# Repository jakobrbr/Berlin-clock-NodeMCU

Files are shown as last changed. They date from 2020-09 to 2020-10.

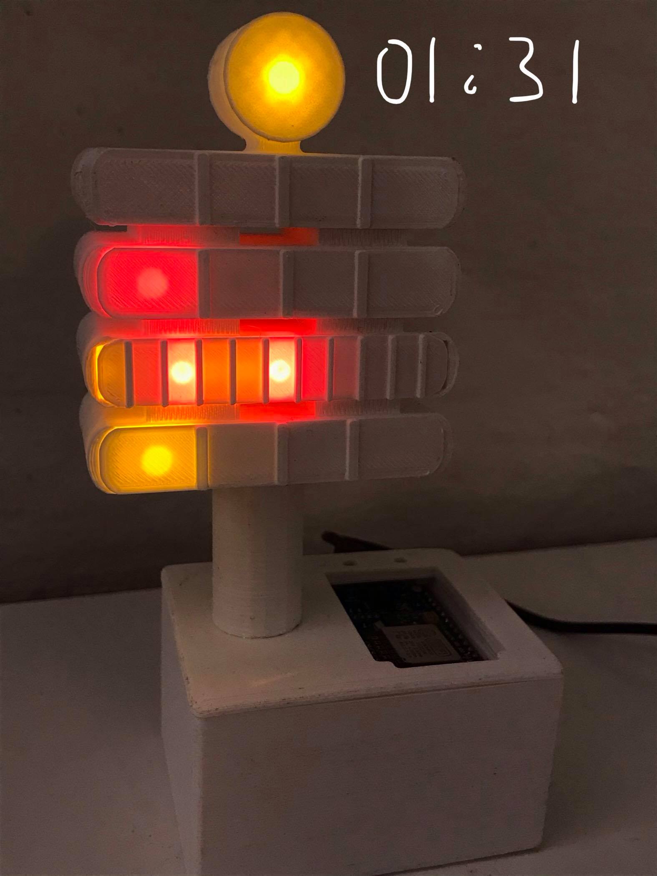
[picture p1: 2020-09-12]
Images/Front.jpg

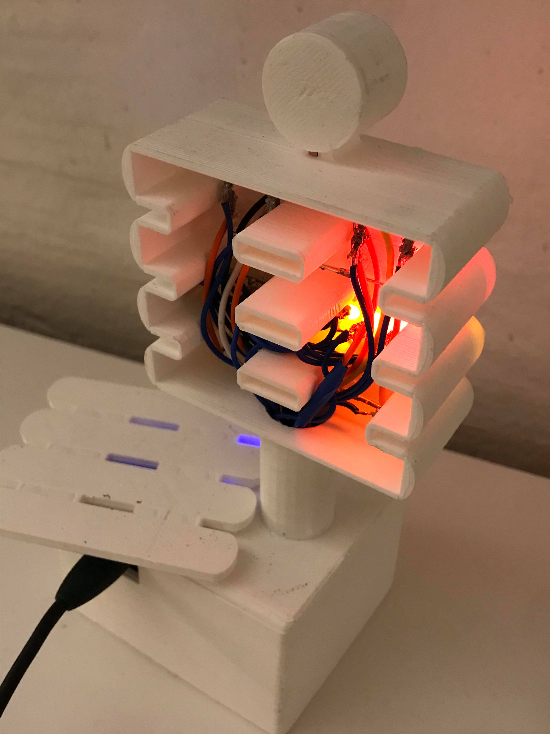
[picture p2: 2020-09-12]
Images/Back.jpg

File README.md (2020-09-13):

# Berlin-clock-NodeMCU
IoT Mengenlehreuhr aka Berlin clock made using ESP8266 NodeMCU and two 74HC595 shift registers.

The clock is based on a real clock that was installed in Berlin in 1975. My goal was to replicate the original design as best as I could, in a small "desktop form factor". 
You can read much more about the original clock and how to tell the time on [Wikipedia](https://en.wikipedia.org/wiki/Mengenlehreuhr).

This DIY version of the Berlin clock is far from perfect, since it was my first real Arduino project and my first time designing a 3d-print model. 

**Picture of the finished product:** [Front](Images/Front.jpg) and [back](Images/Back.jpg)
- As you can see, the three red 3mm LEDs I used for row 3 were too bright compared to the yellow ones. These LEDs were super bright LEDs, and I only used them because I didn't have anything else available. Normal clear 3mm LEDs would have been enough (5mm for row 1,2 and 4). 

## How it works:
The clock uses the WiFi capabilities of the NodeMCU to always have the correct time without the need of a clock module. 
When powered on, the NodeMCU connects to the internet with the network credentials you entered in the arduino code. Then the NodeMCU requests and recieves the current time from an NTP server and displays it using the 24 LEDs. The code used to get time from an NTP server comes from [randomnerdtutorials.com](https://randomnerdtutorials.com/esp8266-nodemcu-date-time-ntp-client-server-arduino/). The LEDs are divided into two LED matrices that are controlled by two 74HC595 shift registers. This reduces the number of NodeMCU pins in use greatly, however one could easily manage to use even less. 
The NodeMCU is powered via a micro USB cable.

[**Arduino code**](Mengenlehreuhr/Mengenlehreuhr.ino)

### LED matrices
In order to limit the amount of I/O pins in use, two 74HC595 shift registers are used to control two LED matrices.
The first marix (matrix1) is a 4x4 matrix containing row 1, 2 and 4 of the clock (counting from the top - see [image](https://commons.wikimedia.org/wiki/File:Berlin-Uhr-1650-1705.gif#/media/File:Berlin-Uhr-1650-1705.gif)). Note that only 3 rows of matrix1 are in use. Matrix1 row 4 represents LED row 4 on the clock; this means that matrix1 row 3 is "empty". The second matrix (matrix2) is a 4x4 matrix containing all elleven elements of LED row 3. See my diagrams in [**Schematic.pdf**](Schematic.pdf).

The code used to multiplex LEDs with a 74HC595 comes from [this instructables by Amanda Ghassaei](https://www.instructables.com/id/Multiplexing-with-Arduino-and-the-74HC595/).

## Schematics
All pin connections and schematics diagrams of the LED matrices can be found in [**Schematic.pdf**](Schematic.pdf).
The seconds indicator LED uses D4 and GND on the NodeMCU. I used 5mm LEDs for row 1, 2 and 3 and 3mm LEDs for row 4. I wouldn't use diffused LEDs, since they are too dim to shine through the front panels. (But if you don't plan on using the panels, diffused LEDs are perfect)

## 3D printed case
I used tinkercad.com to create [all 3d models](3d_models). Everything was printed in white PLA, which ensured that the front panels were translucent enough for the LEDs to shine through.
You may want to change the size and or thickness of the front panels to get your desired look and fit. I included an optional cover for the box, to cover the bright blue light from the NodeMCU, however it fits a bit loose. The tube is supposed to guide the wires from the LEDs down to the box that contains the shift registers, NodeMCU and resistors. The round hole in the box is too small for the tube, so you will either have make it larger or glue the parts together.

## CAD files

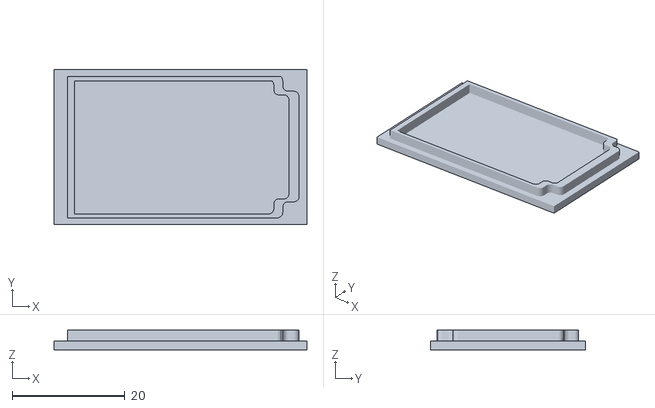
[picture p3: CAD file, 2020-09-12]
3d_models/Optional-cover-for-nodemcu.stl
44.8 x 27.5 x 3.50

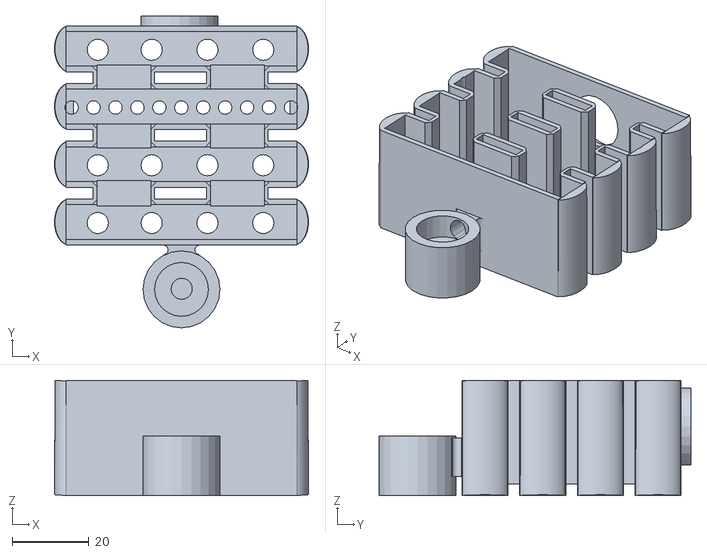
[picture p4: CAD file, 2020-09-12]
3d_models/Berlin-clock-(LEDholder).stl
66.0 x 81.0 x 30.0

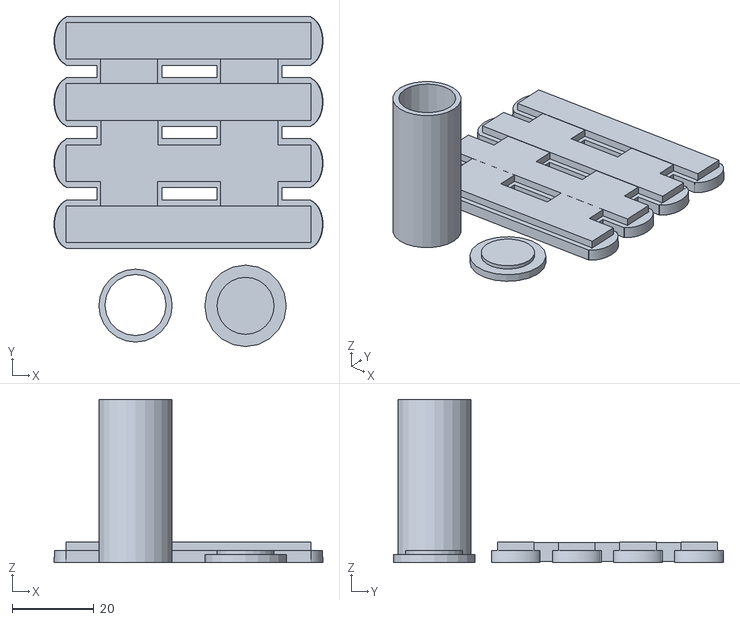
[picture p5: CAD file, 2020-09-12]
3d_models/Tube-and-removable-backplates.stl
66.0 x 81.0 x 40.0

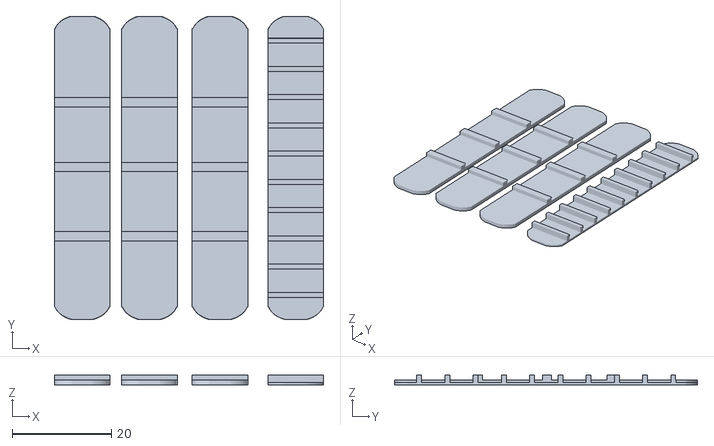
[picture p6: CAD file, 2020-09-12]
3d_models/Front-panels.stl
54.4 x 61.2 x 2.00

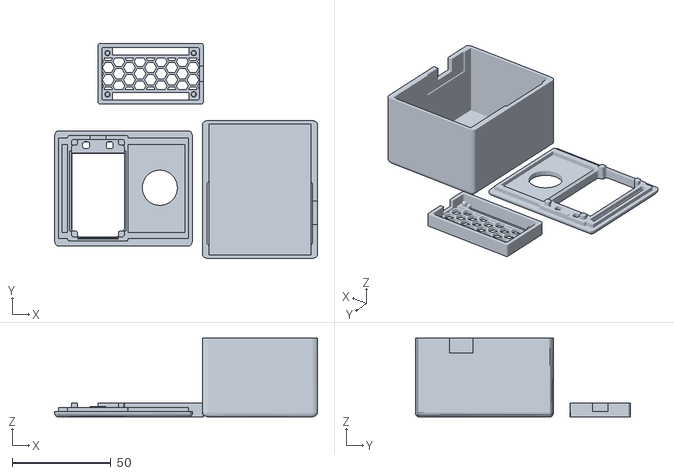
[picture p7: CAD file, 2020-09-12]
3d_models/Box-w-lid-and-nodemcu-holder.stl
133.4 x 109.1 x 40.0

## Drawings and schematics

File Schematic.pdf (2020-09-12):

## Matrix 1 (row 1, 2, 4)

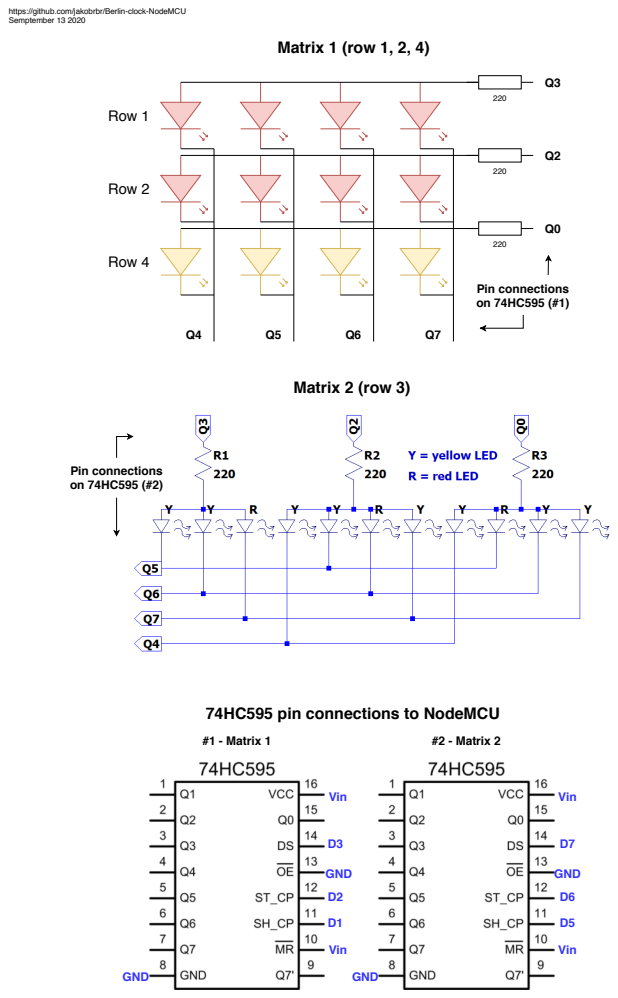
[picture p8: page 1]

https://github.com/jakobrbr/Berlin-clock-NodeMCU
Semptember 13 2020

74HC595 pin connections to NodeMCU

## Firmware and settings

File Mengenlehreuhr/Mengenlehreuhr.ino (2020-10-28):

/*
 * Mengenlehreuhr aka Berlin Clock - a 24 hour LED WiFi clock
 * ESP8266 NodeMCU & 74HC595
 * by Jakob Rud Bernhardt
 * July 2020
 * https://github.com/jakobrbr/Berlin-clock-NodeMCU
 * https://RandomNerdTutorials.com/esp8266-nodemcu-date-time-ntp-client-server-arduino/
 * https://www.instructables.com/id/Multiplexing-with-Arduino-and-the-74HC595/
 */
#include <ESP8266WiFi.h>
#include <NTPClient.h>
#include <WiFiUdp.h>

// Replace with your network credentials
const char *ssid     = "Your wifi network name";
const char *password = "Your wifi password";

// Define NTP Client to get time
WiFiUDP ntpUDP;
NTPClient timeClient(ntpUDP, "pool.ntp.org");

int oldSecond, oldMinute, oldHour;

// seconds LED
#define secPin D4
// matrix 1; row 1, 2 and 4
#define latchPin1 D2
#define clockPin1 D1
#define dataPin1 D3
// matrix 2; row 3
#define latchPin2 D6
#define clockPin2 D5
#define dataPin2 D7

//looping variables
byte i;
byte j;

//storage variable
byte dataToSend1;
byte dataToSend2;

//storage for led states, 4 bytes
byte ledData1[4]; // storage array for row 1, 2 and 4
byte ledData2[4]; // storage array for row 3

void setup() {
  // Initialize Serial Monitor
  Serial.begin(115200);

  //set pins as output
  pinMode(secPin, OUTPUT);
  pinMode(latchPin1, OUTPUT);
  pinMode(clockPin1, OUTPUT);
  pinMode(dataPin1, OUTPUT);
  pinMode(latchPin2, OUTPUT);
  pinMode(clockPin2, OUTPUT);
  pinMode(dataPin2, OUTPUT);
  
  // Connect to Wi-Fi
  WiFi.begin(ssid, password);

  // Initialize a NTPClient to get time
  timeClient.begin();
  timeClient.setTimeOffset(7200);// set offset time in seconds to adjust timezone, GMT = 0 and GMT+2 = 7200
}

void secLED(int currentSecond) {
  // top blinking LED, on/off for one second at a time
  int odd = currentSecond%2;
  if(odd){
    digitalWrite(secPin,HIGH);
  } else if(!odd) {
    digitalWrite(secPin,LOW);
  }
}

void rowOne(int currentHour){
  // four elements, each one is 5 hours
  if (currentHour < 5) {  
    ledData1[0] = 0;
  } else if (currentHour < 10) {  
    ledData1[0] = 1;
  } else if (currentHour < 15) {
    ledData1[0] = 3;
  } else if (currentHour < 20) {
    ledData1[0] = 7;
  } else {
    ledData1[0] = 15;
  } 
}

void rowTwo(int currentHour){
  // four elements, each element is one hour
  int n = currentHour % 5;// integer n is the number of lit LEDs 

  switch (n) {
    case 1:
      // one LED
      ledData1[1] = 1;
      break;
    case 2:
    // two LEDs
      ledData1[1] = 3;
      break;
    case 3:
      // three LEDs
      ledData1[1] = 7;
      break;
    case 4:
      // four LEDs
      ledData1[1] = 15;
      break;
    default:
      ledData1[1] = 0;
    break; 
  }
}

void rowThree(int currentMinute){ 
  //11 elements, each element represents 5 minutes

  if (currentMinute < 5) {
    // full blank row
    ledData2[0] = 0;
    ledData2[1] = 0;
    ledData2[2] = 0;
    ledData2[3] = 0;
  } else if (currentMinute < 10) {
      // one LED
      ledData2[0] = 3;
      ledData2[1] = 0;
      ledData2[2] = 0;
      ledData2[3] = 0;
  } else if (currentMinute < 15) {
       // two LEDs
      ledData2[0] = 7;
      ledData2[1] = 0;
      ledData2[2] = 0;
      ledData2[3] = 0;
  } else if (currentMinute < 20) {
      // three LEDs
      ledData2[0] = 15;
      ledData2[1] = 0;
      ledData2[2] = 0;
      ledData2[3] = 0;
  } else if (currentMinute < 25) {
      // four
      ledData2[0] = 15;
      ledData2[1] = 1;
      ledData2[2] = 0;
      ledData2[3] = 0;
  } else if (currentMinute < 30) {
      // five
      ledData2[0] = 15;
      ledData2[1] = 3;
      ledData2[2] = 0;
      ledData2[3] = 0;
  } else if (currentMinute < 35) {
      // six
      ledData2[0] = 15;
      ledData2[1] = 7;
      ledData2[2] = 0;
      ledData2[3] = 0;
  } else if (currentMinute < 40) {
      // seven
      ledData2[0] = 15;
      ledData2[1] = 15;
      ledData2[2] = 0;
      ledData2[3] = 0;
  } else if (currentMinute < 45) {
      // eight
      ledData2[0] = 15;
      ledData2[1] = 15;
      ledData2[2] = 0;
      ledData2[3] = 1;
  } else if (currentMinute < 50) {
      // nine
      ledData2[0] = 15;
      ledData2[1] = 15;
      ledData2[2] = 0;
      ledData2[3] = 3;
  } else if (currentMinute < 55) {
      // ten
      ledData2[0] = 15;
      ledData2[1] = 15;
      ledData2[2] = 0;
      ledData2[3] = 7;
  } else if (currentMinute < 60) {
      // elleven
      ledData2[0] = 15;
      ledData2[1] = 15;
      ledData2[2] = 0;
      ledData2[3] = 15;
  }
}

void rowFour(int currentMinute){// bottom row
  // four LEDs light up, with one LED corresponding to one minute passed
  // after five minutes the entire row will turn blank and start over
  
  int lastDigit = currentMinute % 10; // gets last digit of minutes

  if (lastDigit == 1 || lastDigit == 6) {
    // one LED
    ledData1[3] = 1;
  } else if (lastDigit == 2 || lastDigit == 7) {
    // two LEDs
    ledData1[3] = 3;
  } else if (lastDigit == 3 || lastDigit == 8) {
    // three LEDs
    ledData1[3] = 7;
  } else if (lastDigit == 4 || lastDigit == 9) {
    // four LEDs
    ledData1[3] = 15;
  } else if (lastDigit == 5 || lastDigit == 0) {
    // full blank row
    ledData1[3] = 0;
  } 
}


void loop() {
  timeClient.update();
  unsigned long epochTime = timeClient.getEpochTime();
  int currentMinute = timeClient.getMinutes();
  int currentSecond = timeClient.getSeconds();
  int currentHour = timeClient.getHours();

  // to prevent excessive calculations, the LED update functions are only run if the time has changed
  if (currentSecond != oldSecond){
    secLED(currentSecond);
  } 
  if (currentMinute != oldMinute) {
    rowFour(currentMinute);
    secLED(currentSecond); // the seconds-LED is updated again in case the previous update function is slow
    rowThree(currentMinute);
    if (currentHour != oldHour) {
      secLED(currentSecond); // the seconds-LED is once again updated
      rowOne(currentHour);
      rowTwo(currentHour);
    }
  }

  // "demultiplexing"-code: _________________________________________________________
   for (i=0;i<4;i++){
    //send data from ledData to each row, one at a time
    byte dataToSend1 = (1 << (i+4)) | (15 & ~ledData1[i]); // for LED matrix containing row 1, 2 and 4
    byte dataToSend2 = (1 << (i+4)) | (15 & ~ledData2[i]); // for LED matrix containing row 3
      
    // set latch pins low so the LEDs don't change while sending in bits
    digitalWrite(latchPin1, LOW);
    digitalWrite(latchPin2, LOW);
    
    // shift out the bits of dataToSend to the 74HC595
    // shift out(dataPin, clockPin, LSBFIRST, dataToSend)
    for (j=0;j<8;j++){
      // row 1, 2 and 4
      digitalWrite(clockPin1,LOW);
      digitalWrite(dataPin1,((dataToSend1>>j)&1));
      digitalWrite(clockPin1,HIGH);
      // row 3
      digitalWrite(clockPin2,LOW);
      digitalWrite(dataPin2,((dataToSend2>>j)&1));
      digitalWrite(clockPin2,HIGH);
    }
    //set latch pins high- this sends data to outputs so the LEDs will light up
    digitalWrite(latchPin1, HIGH);
    digitalWrite(latchPin2, HIGH);   
  }
  // end of "demultiplexing"-code __________________________________________________
  
  oldSecond = currentSecond;
  oldMinute = currentMinute;
  oldHour = currentHour;
}
